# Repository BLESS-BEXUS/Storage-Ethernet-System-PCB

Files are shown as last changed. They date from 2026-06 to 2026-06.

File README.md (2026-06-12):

<p align="center">
    <br>
    <a href="https://bless-bexus.es">
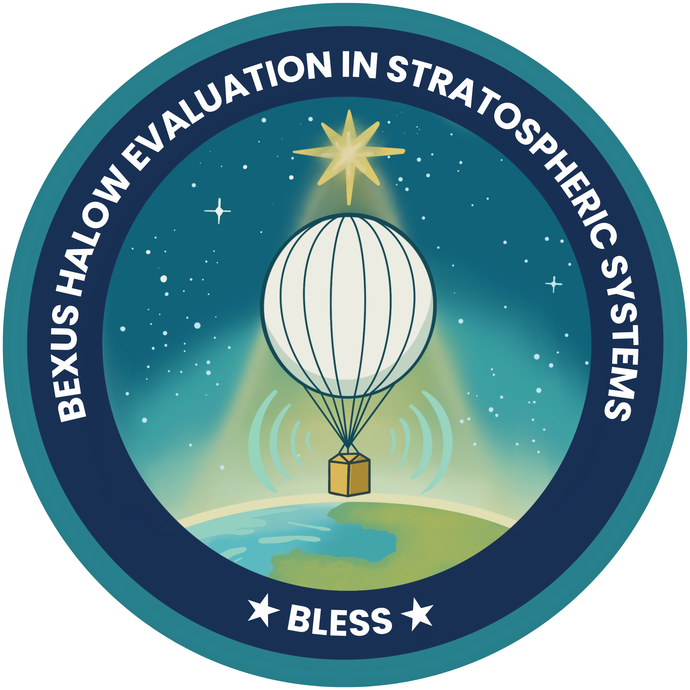
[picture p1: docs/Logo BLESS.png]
BLESS Logo
        
    </a>
</p>
<h1 align="center">Storage & Ethernet System</h1>
<p align="center">
A compact PCB designed to provide redundant onboard storage and wired Ethernet connectivity for embedded systems where robustness, data integrity and easy integration are key.
</p>
<p align="center">
    
    
    <br>
    <a href="https://rexusbexus.net/">
        
    </a>
</p>

---

### Overview

The main goal of this PCB is to improve the reliability of embedded data logging and communication systems.

It is especially useful in applications where removable media such as microSD cards may be affected by vibration, mechanical stress, poor contact or harsh environmental conditions.

The board is designed to support:

- Reliable onboard data storage.
- Redundant logging.
- Wired Ethernet communication.
- Compact integration.
- Post-operation data recovery.

### Main Features

- Dual SPI NOR Flash memories.
- Independent chip-select lines for each memory.
- WIZnet W5500 hardware TCP/IP Ethernet controller.
- SiTime SiT5000 25 MHz TCXO clock source.
- SPI interface with the main controller.
- ESD-aware external interface design.
- Ethernet analog supply isolation.
- Custom KiCad symbols, footprints and 3D models.

---

<h3 align="center">Contributing</h3>

<p align="center">
·
    <a href="./CODE_OF_CONDUCT.md">Code of Conduct</a>
    ·
    <a href="./CONTRIBUTING.md">Contributing Guide</a>
    ·
</p>

<p align="center">We welcome collaboration from the aerospace and software community. For major changes or data inquiries, please open an issue first.</p>

<h3 align="center">License</h3>

<pre align="center">Copyright © 2025-2026 The BLESS Project Team<br><br>This Source Code Form is subject to the terms of the Mozilla Public<br>License, v. 2.0. If a copy of the MPL was not distributed with this<br>file, You can obtain one at http://mozilla.org/MPL/2.0/.</pre>

<h3 align="center">Credits & Team</h3>

<p align="center">Supported by the REXUS/BEXUS Program and our generous sponsors.</p>
<p align="center">
    <a href="https://github.com/BLESS-BEXUS/Storage-Ethernet-System-PCB/graphs/contributors">
        
    </a>
</p>

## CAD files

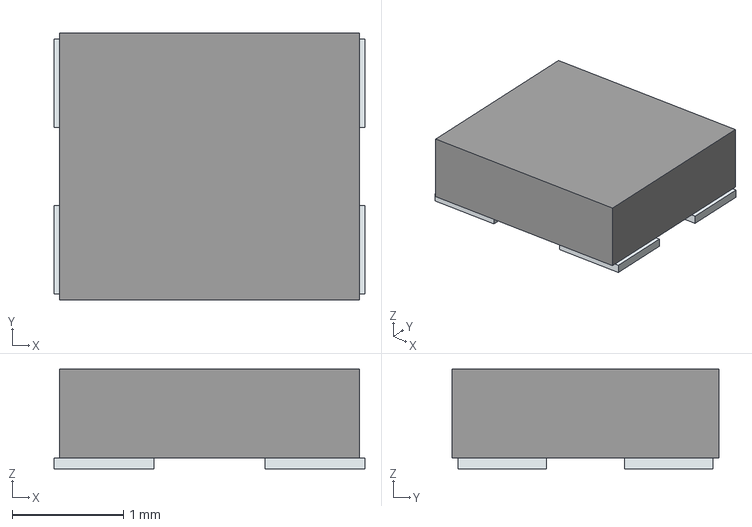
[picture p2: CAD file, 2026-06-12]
STEPS/SIT5000AICGE-33N0-25.000000X.stp
2.80 x 2.40 x 0.9 mm
Pins

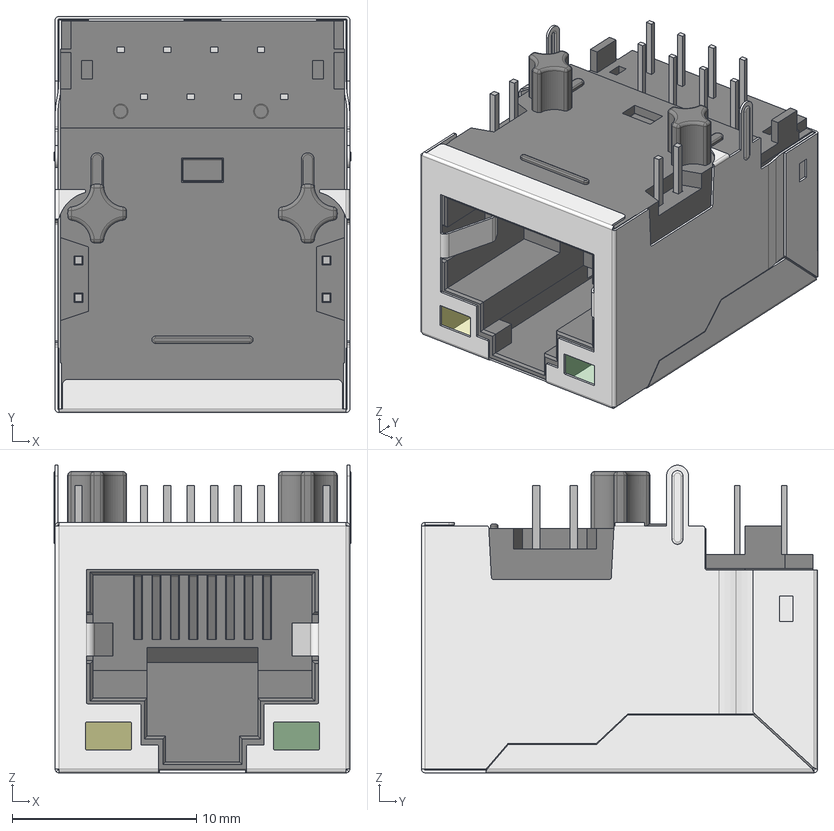
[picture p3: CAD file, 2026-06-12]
STEPS/74980104400.stp
16.1 x 21.5 x 16.7 mm
Insulator
LED
Insulator_2
pins2
Shielding

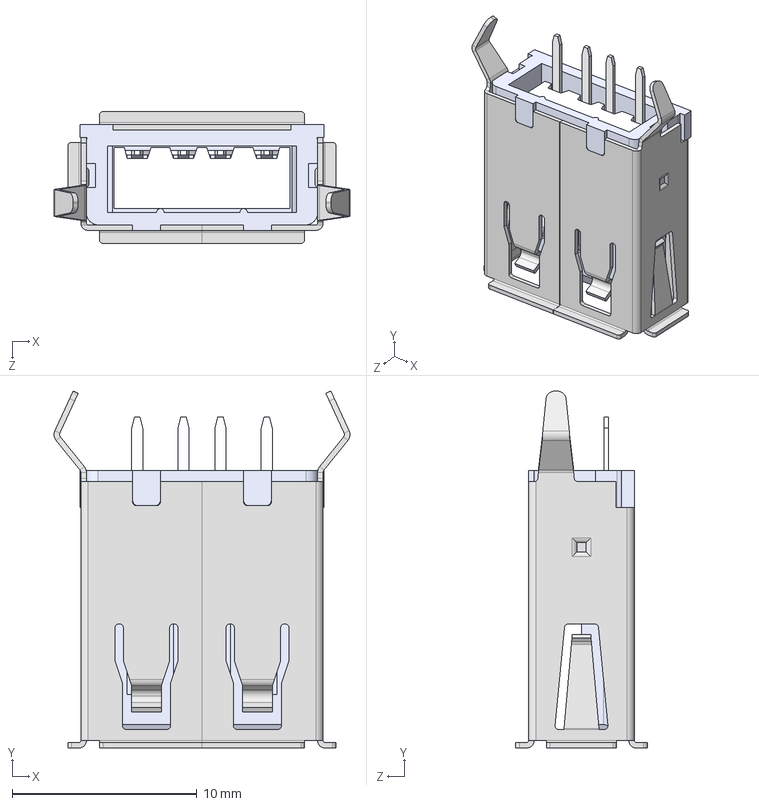
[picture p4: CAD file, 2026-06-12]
STEPS/614004135023.stp
16.0 x 19.3 x 7.12 mm
Insulator
Pin x 4
Shielding
Insulator2

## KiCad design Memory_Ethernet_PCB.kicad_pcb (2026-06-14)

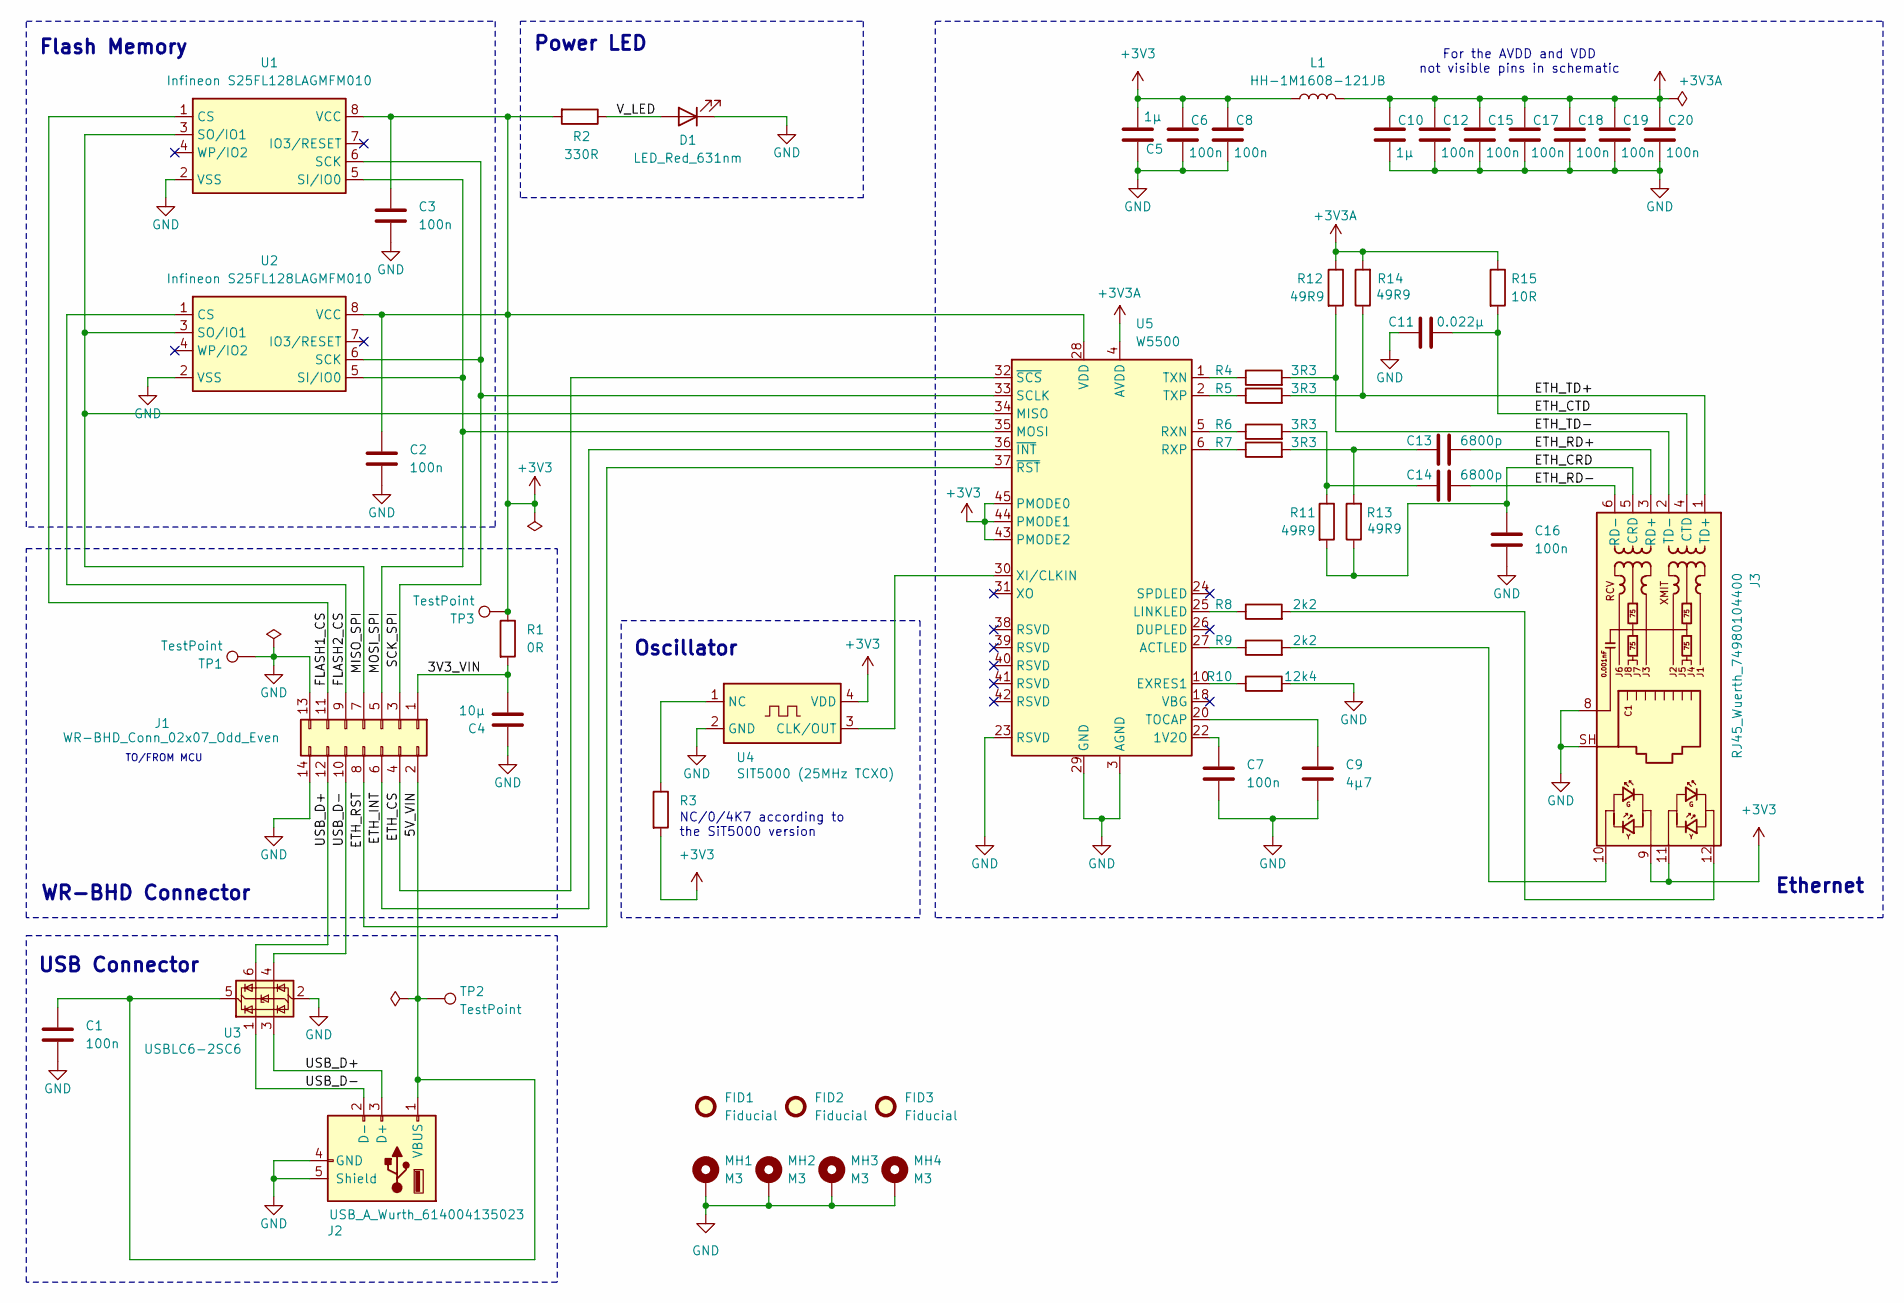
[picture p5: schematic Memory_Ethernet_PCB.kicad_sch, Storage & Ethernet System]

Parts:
C1, C2, C3, C6, C7, C8, C12, C15, C16, C17, C18, C19, C20: 100n; C_0805_2012Metric; Manufacturer Part Number GCD21BR71H104KA01K; LCSC C21025875
C4: 10µ; C_1206_3216Metric; Manufacturer Part Number CGA5L1X7R1C106K160AC; LCSC C2168241
C5, C10: 1µ; C_0805_2012Metric; Manufacturer Part Number KGM21AR71C105JU; LCSC C20219896
C9: 4µ7; C_0805_2012Metric; Manufacturer Part Number GCM21BM8EH475KE08L
C11: 0.022µ; C_0805_2012Metric; Manufacturer Part Number GCM21B5C2A223JE02L; LCSC C21025875
C13, C14: 6800p; C_0805_2012Metric; Manufacturer Part Number GRM21AR7LU682KW01D
D1: LED_Red_631nm; LED_0603_1608Metric; Manufacturer Part Number LTST-C190KRKT; LCSC C94869
FID1, FID2, FID3: Fiducial; Fiducial_1mm_Mask2mm
J1: WR-BHD_Conn_02x07_Odd_Even; IDC-Header_2x07_P2.54mm_Vertical
J2: USB_A_Wurth_614004135023
J3: RJ45_Wuerth_74980104400
L1: HH-1M1608-121JB; L_0603_1608Metric
MH1, MH2, MH3, MH4: M3; MountingHole_3.2mm_M3_Pad_Via
R1: 0R; R_0603_1608Metric; Manufacturer Part Number RC0603JR-070RL; LCSC C95177
R2: 330R; R_0603_1608Metric; Manufacturer Part Number CR0603-FX-3300ELF; LCSC C2077087
R3: R_0805_2012Metric; Manufacturer Part Number AC0805JR-134K7L; LCSC C6457914
R4, R5, R6, R7: 3R3; R_0805_2012Metric; Manufacturer Part Number RC0805FR-073R3P; LCSC C20162778
R8, R9: 2k2; R_0805_2012Metric; Manufacturer Part Number AC0805FR-7W2K2L; LCSC C5545398
R10: 12k4; R_0805_2012Metric; Manufacturer Part Number ERJ-UP6F1242V; LCSC C7184516
R11, R12, R13, R14: 49R9; R_0805_2012Metric; Manufacturer Part Number RT73F2A49R9BTD; LCSC C95177
R15: 10R; R_0805_2012Metric; Manufacturer Part Number CRGP0805F10R; LCSC C2083624
TP1, TP2, TP3: TestPoint; TestPoint_Pad_D1.0mm
U1, U2: Infineon S25FL128LAGMFM010; SOIC-8_5.3x5.3mm_P1.27mm; LCSC C2944449
U3: USBLC6-2SC6; SOT-23-6; LCSC C7519
U4: SIT5000 (25MHz TCXO); Oscillator_SMD_SiT_PQFN-4Pin_2.5x2.0mm
U5: W5500; LQFP-48_7x7mm_P0.5mm

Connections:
+3V3: C2.1, C3.1, C5.2, C6.1, C8.1, J3.9, J3.11, L1.1, R1.1, R2.2, R3.2, TP3.1 (1_1), U1.8 (VCC), U2.8 (VCC), U4.4 (VDD), U5.28 (VDD), U5.43 (PMODE2), U5.44 (PMODE1), U5.45 (PMODE0)
+3V3A: C10.1, C12.1, C15.1, C17.1, C18.1, C19.1, C20.1, L1.2, R12.1, R14.2, R15.1, U5.4 (AVDD), U5.8 (AVDD), U5.11 (AVDD), U5.15 (AVDD), U5.17 (AVDD), U5.21 (AVDD)
/3V3_VIN: C4.1, J1.1, R1.2
/5V_VIN: C1.1, J1.2, J2.1 (VBUS), TP2.1 (1_1), U3.5 (VBUS)
/ETH_CRD: C16.1, J3.5 (CRD), R11.2, R13.1
/ETH_CS: J1.4, U5.32 (~SCS)
/ETH_CTD: C11.2, J3.4 (CTD), R15.2
/ETH_INT: J1.6, U5.36 (~INT)
/ETH_RD+: C13.2, J3.3 (RD+)
/ETH_RD-: C14.2, J3.6 (RD-)
/ETH_RST: J1.8, U5.37 (~RST)
/ETH_TD+: J3.1 (TD+), R5.2, R14.1
/ETH_TD-: J3.2 (TD-), R4.2, R12.2
/FLASH1_CS: J1.11, U1.1 (CS)
/FLASH2_CS: J1.9, U2.1 (CS)
/MISO_SPI: J1.7, U1.3 (SO/IO1), U2.3 (SO/IO1), U5.34 (MISO)
/MOSI_SPI: J1.5, U1.5 (SI/IO0), U2.5 (SI/IO0), U5.35 (MOSI)
/SCK_SPI: J1.3, U1.6 (SCK), U2.6 (SCK), U5.33 (SCLK)
/USB_D+: J1.12, J2.3 (D+), U3.3 (I/O2), U3.6 (I/O1)
/USB_D-: J1.10, J2.2 (D-), U3.1 (I/O1), U3.4 (I/O2)
/V_LED: D1.2 (A), R2.1
GND: C1.2, C2.2, C3.2, C4.2, C5.1, C6.2, C7.2, C8.2, C9.2, C10.2, C11.1, C12.2, C15.2, C16.2, C17.2, C18.2, C19.2, C20.2, D1.1 (K), J1.13, J1.14, J2.4 (GND), J2.5 (Shield), J3.8, J3.SH, MH1.1 (1_1), MH2.1 (1_1), MH3.1 (1_1), MH4.1 (1_1), R10.2, TP1.1 (1_1), U1.2 (VSS), U2.2 (VSS), U3.2 (GND), U4.2 (GND), U5.3 (AGND), U5.9 (AGND), U5.14 (AGND), U5.16 (AGND), U5.19 (AGND), U5.23 (RSVD), U5.29 (GND), U5.48 (AGND)
unnamed: C13.1, R7.2, R13.2
unnamed: C14.1, R6.2, R11.1
unnamed: J3.10, R9.2
unnamed: J3.12, R8.2
unnamed: U4.3 (CLK/OUT), U5.30 (XI/CLKIN)
unnamed: R3.1, U4.1 (NC)
unnamed: C7.1, U5.22 (1V2O)
unnamed: R9.1, U5.27 (ACTLED)
unnamed: R10.1, U5.10 (EXRES1)
unnamed: R8.1, U5.25 (LINKLED)
unnamed: R6.1, U5.5 (RXN)
unnamed: R7.1, U5.6 (RXP)
unnamed: C9.1, U5.20 (TOCAP)
unnamed: R4.1, U5.1 (TXN)
unnamed: R5.1, U5.2 (TXP)

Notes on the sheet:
TO/FROM MCU
Power LED
Flash Memory
Ethernet
NC/0/4K7 according to the SiT5000 version
USB Connector
For the AVDD and VDD not visible pins in schematic
WR-BHD Connector
Oscillator

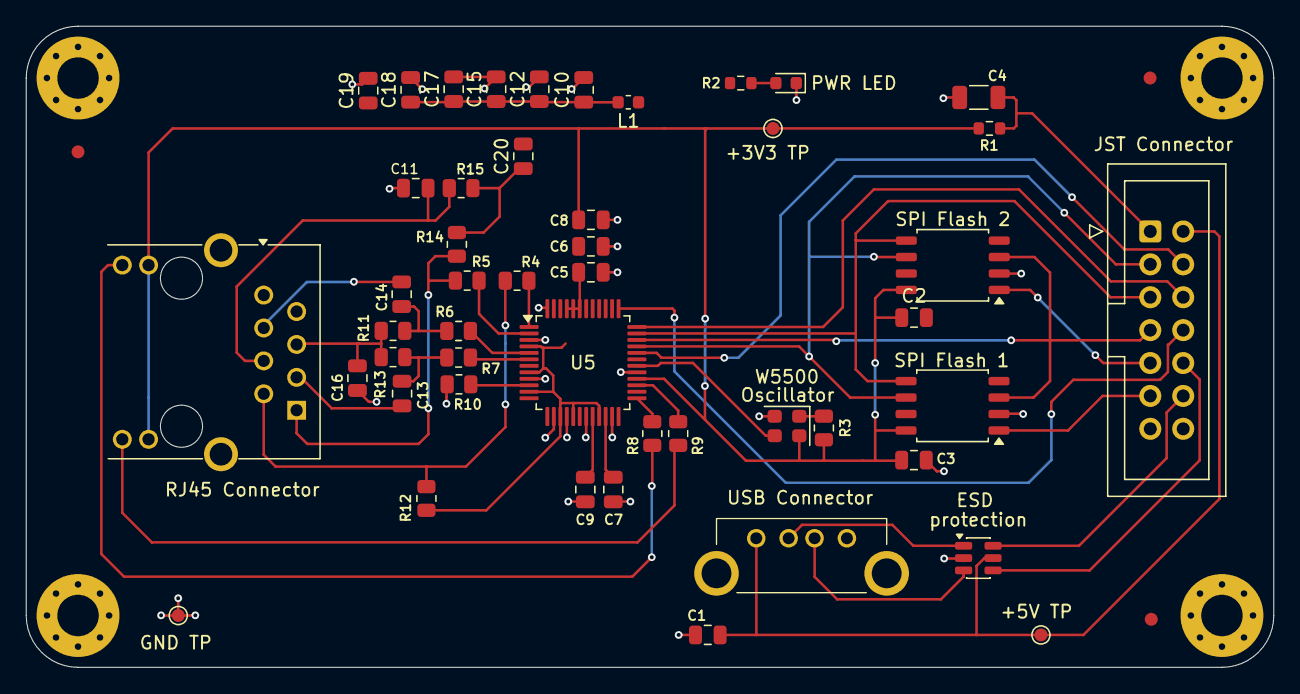
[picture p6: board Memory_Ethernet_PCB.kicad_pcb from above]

Board: 2 copper layers, 96.3 x 49.5 mm, 55 parts (0 on the bottom side), 37 nets.

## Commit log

2026-06-12 Add .gitignore file for KiCad project to exclude temporary and backup files
2026-06-12 git commit -m "Add initial Memory Ethernet PCB KiCad project
    Include the main KiCad project files for the Memory Ethernet PCB:
    schematic, PCB layout, and project configuration. This commit establishes
    the base hardware design to track future changes in version control."
    [Memory_Ethernet_PCB.kicad_pcb, Memory_Ethernet_PCB.kicad_sch]
2026-06-12 Add custom STEP models for non-standard components
    Include 3D STEP models required by components that are not available
    in the default KiCad libraries, ensuring the PCB 3D view and mechanical
    integration remain consistent across the project.
    [614004135023.stp, 74980104400.stp, SIT5000AICGE-33N0-25.000000X.stp]
2026-06-12 Add project-specific KiCad symbol and footprint libraries
    Add the custom schematic symbol library, footprint library, and KiCad
    library tables required to make the PCB project portable and consistent
    across different development environments.
2026-06-12 Remove pcb routing
    [Memory_Ethernet_PCB.kicad_pcb]
2026-06-14 Initial component routing
    [Memory_Ethernet_PCB.kicad_pcb]
2026-06-14 SPI and ETH Routing
    [Memory_Ethernet_PCB.kicad_pcb]
2026-06-14 +3V3 Routing
    [Memory_Ethernet_PCB.kicad_pcb]
